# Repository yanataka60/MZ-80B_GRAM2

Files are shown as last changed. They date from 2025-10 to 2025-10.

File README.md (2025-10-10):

# MZ-80B GRAM2ボード

　MZ-80B OWNER'S MANUAL p67「図4-21 グラフィックメモリ2 MZ-8BK(オプション)」回路図から基板を起こしました。

　本体への装着方法は純正品と同じです。

## 回路図
　KiCadフォルダ内のMZ-80B_GRAM2.pdf参照

[回路図](https://github.com/yanataka60/MZ-80B_GRAM2/blob/main/Kicad/MZ-80B_GRAM2.pdf)
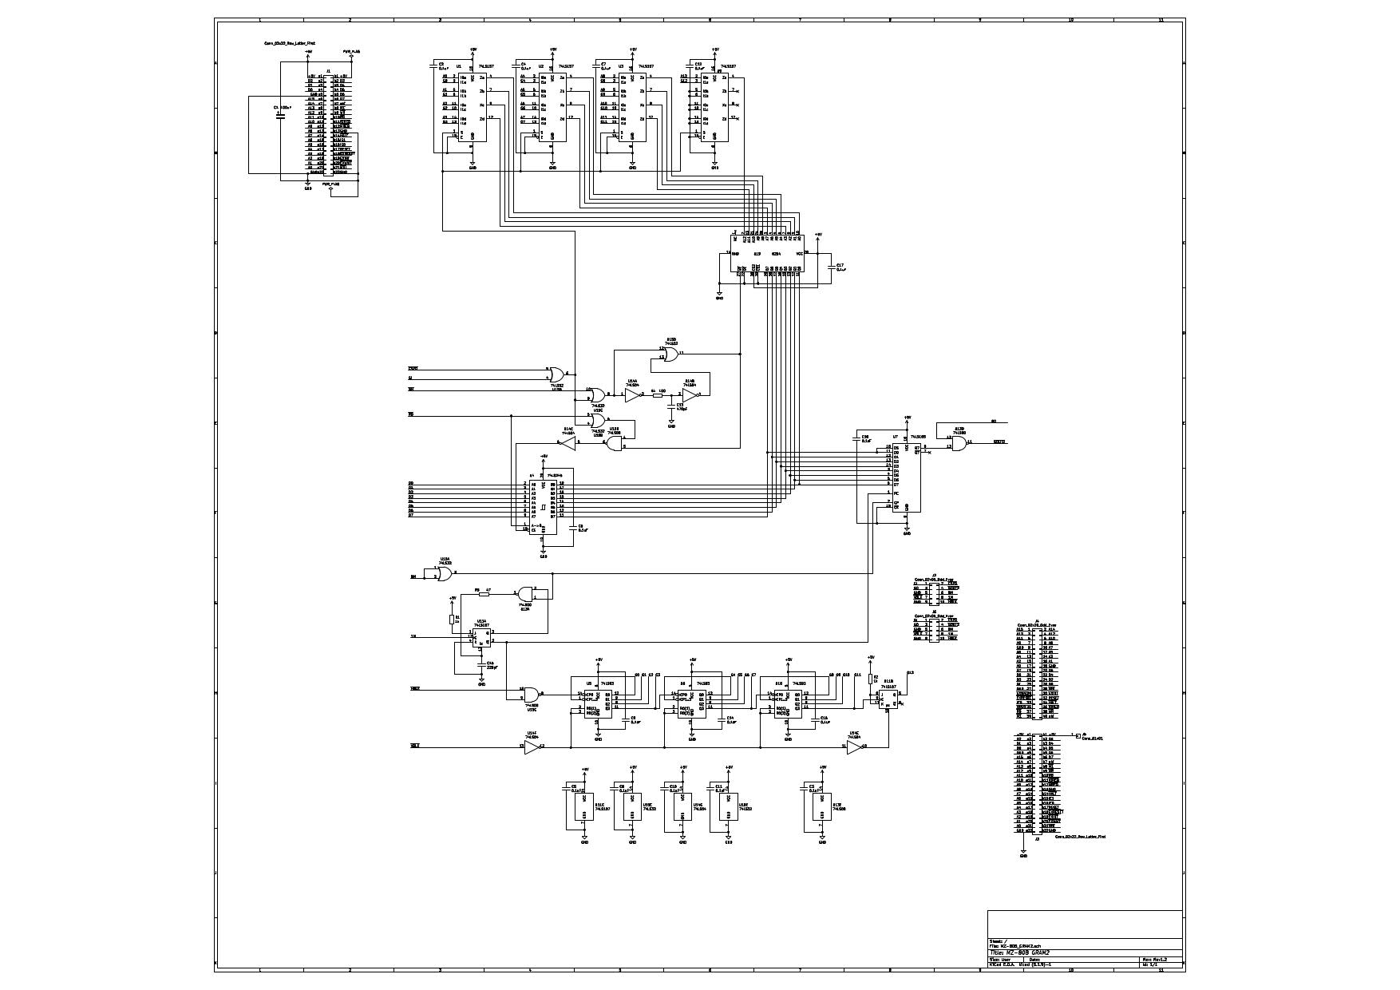
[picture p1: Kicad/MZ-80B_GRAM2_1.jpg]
回路図


## 部品表
|番号|品名|数量|備考|
| --- | --- | --- | --- |
|C1|電解コンデンサ 16V100uF|1||
|C2-C12, C14, C16-C18|積層セラミックコンデンサ 0.1uF|15||
|C13|コンデンサ 470pF|1||
|C15|コンデンサ 220pF|1||
|J2,J3,J4,J5|使用しません|||
|J6|2x5ピンヘッダ|1|秋月電子通商 PH-2x40SG等|
|R1,R2|カーボン抵抗 1k|2||
|R3|カーボン抵抗 47Ω|1||
|R4|カーボン抵抗 100Ω|1||
|U1-U3,U9|74LS157|4|若松通商等|
|U4|74LS245|1|若松通商等|
|U5,U6,U10|74LS93|3|若松通商等|
|U7|74LS165|1|若松通商等|
|U11|74LS107|1|若松通商等|
|U13|74LS00|1|若松通商等|
|U14|74LS04|1|若松通商等|
|U15,U18|74LS32|2|若松通商等|
|U19|8kx8 SRAM 6264|1|若松通商等|
||2x5フラットケーブル|1|4番スロットなら20cm程度、1番スロットなら30cm程度|

## ボードの完成写真
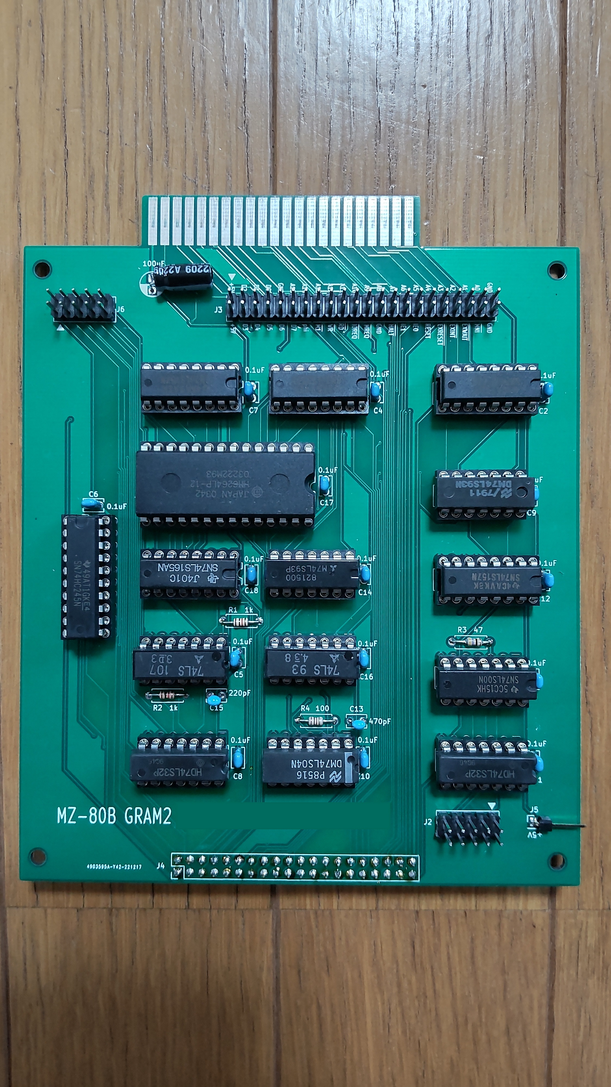
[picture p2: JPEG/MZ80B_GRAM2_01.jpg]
MZ80B_GRAM2_01


## 取付方法
拡張I/Oユニットの1番スロット又は4番スロットにGRAM2ボードを挿し込みます。

GRAM1ボードのJ3とGRAM2ボードのJ6を2x5Pinケーブルで接続します。

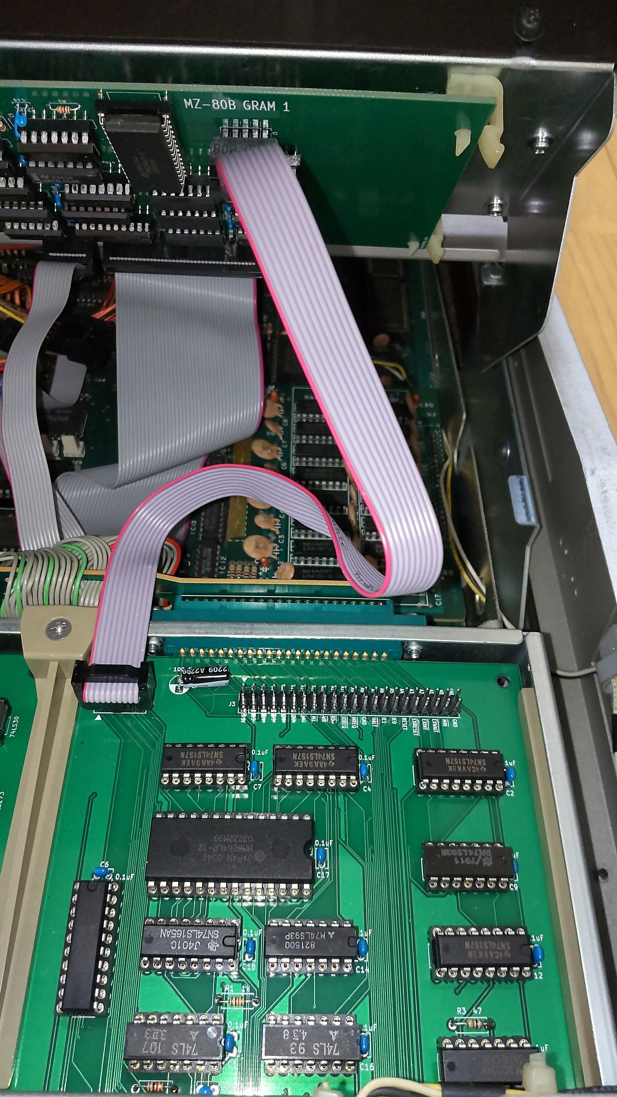
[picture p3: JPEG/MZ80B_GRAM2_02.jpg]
MZ80B_GRAM2_02


## 追記
2025.10.10 回路図のpdfファイルを追加した。

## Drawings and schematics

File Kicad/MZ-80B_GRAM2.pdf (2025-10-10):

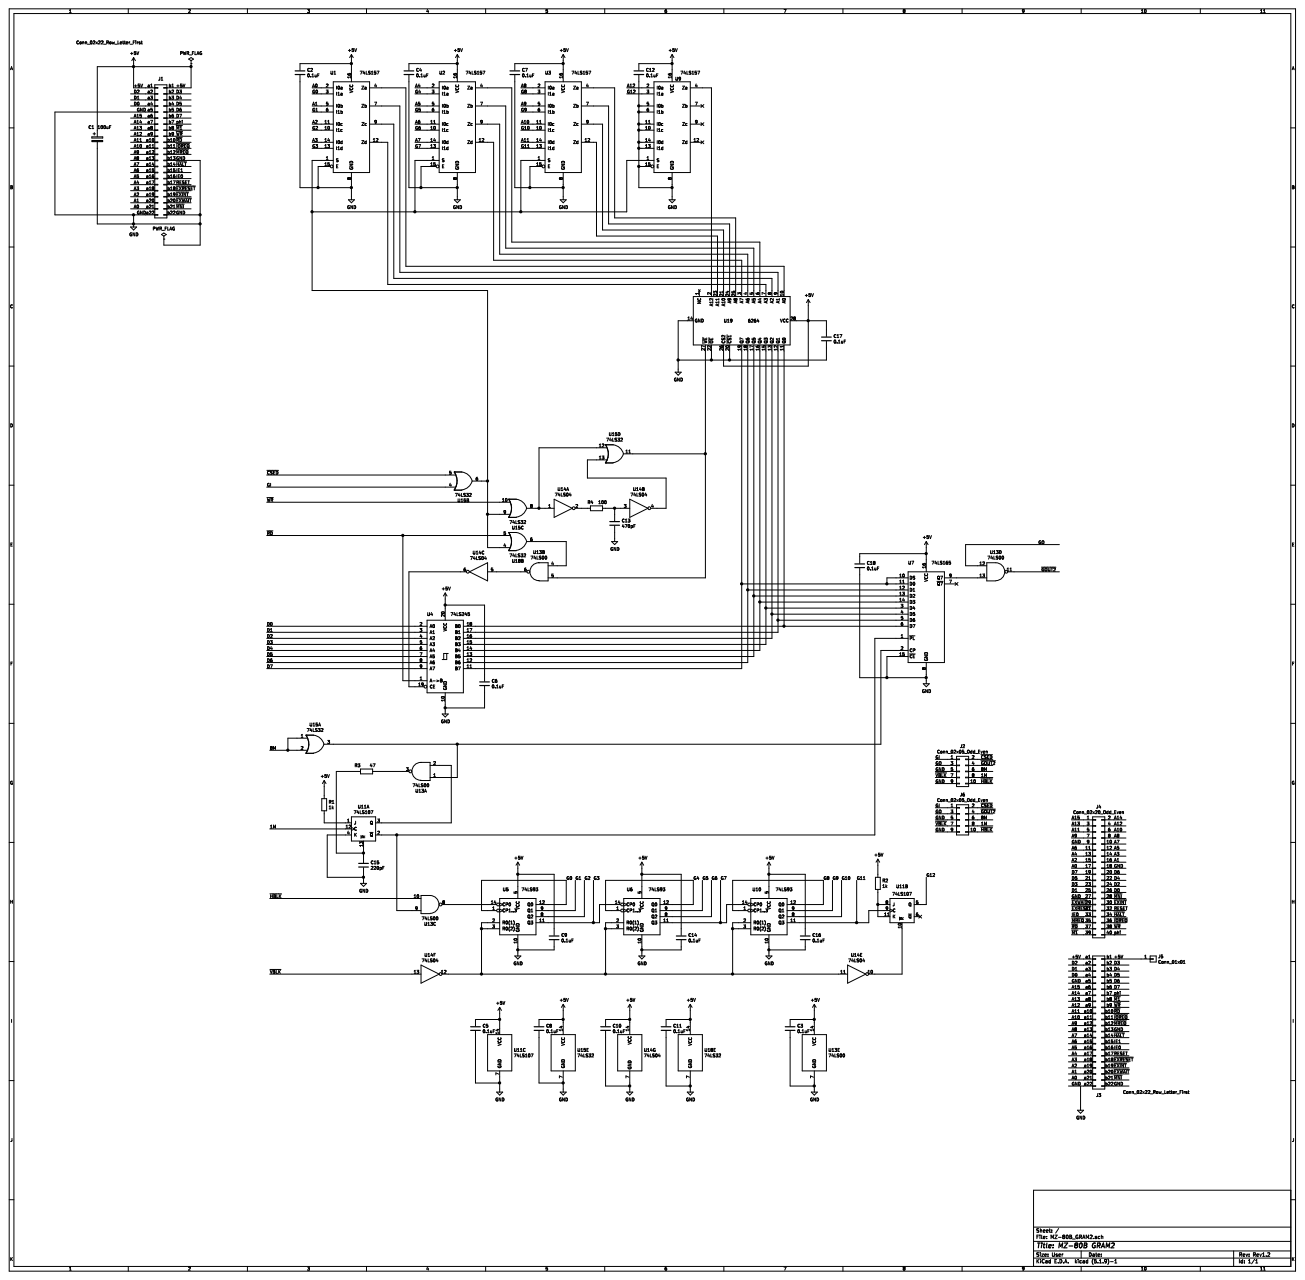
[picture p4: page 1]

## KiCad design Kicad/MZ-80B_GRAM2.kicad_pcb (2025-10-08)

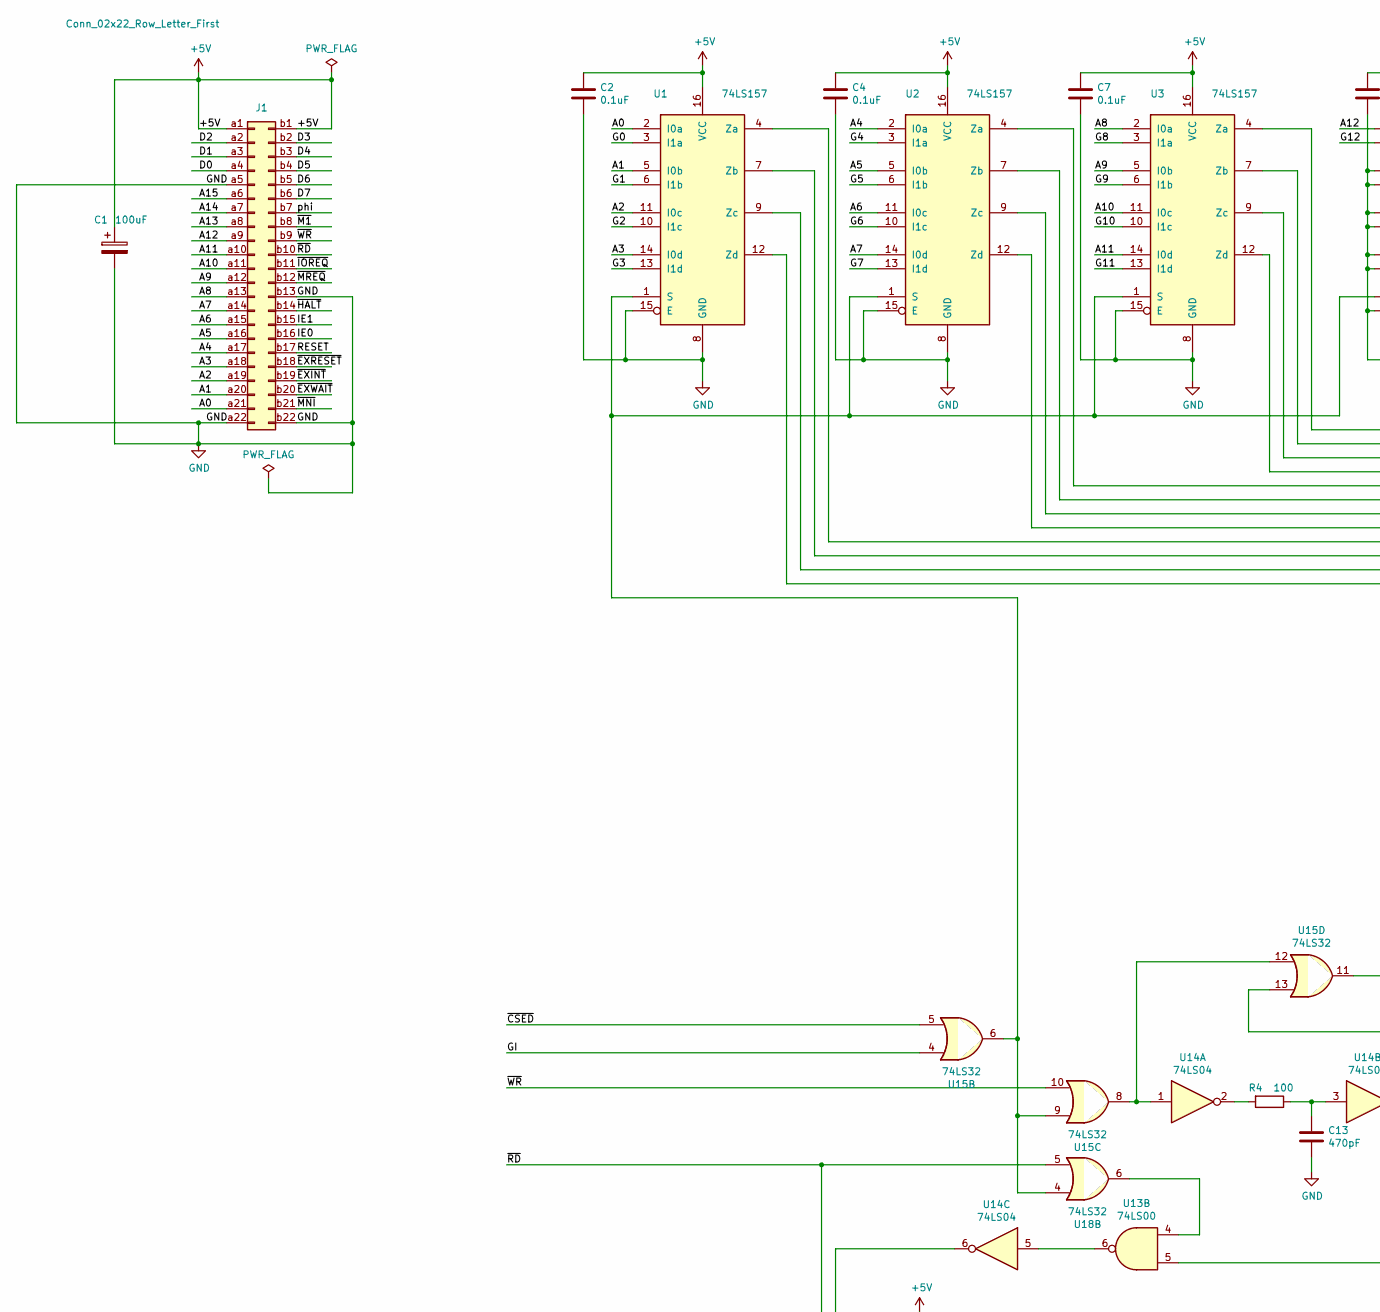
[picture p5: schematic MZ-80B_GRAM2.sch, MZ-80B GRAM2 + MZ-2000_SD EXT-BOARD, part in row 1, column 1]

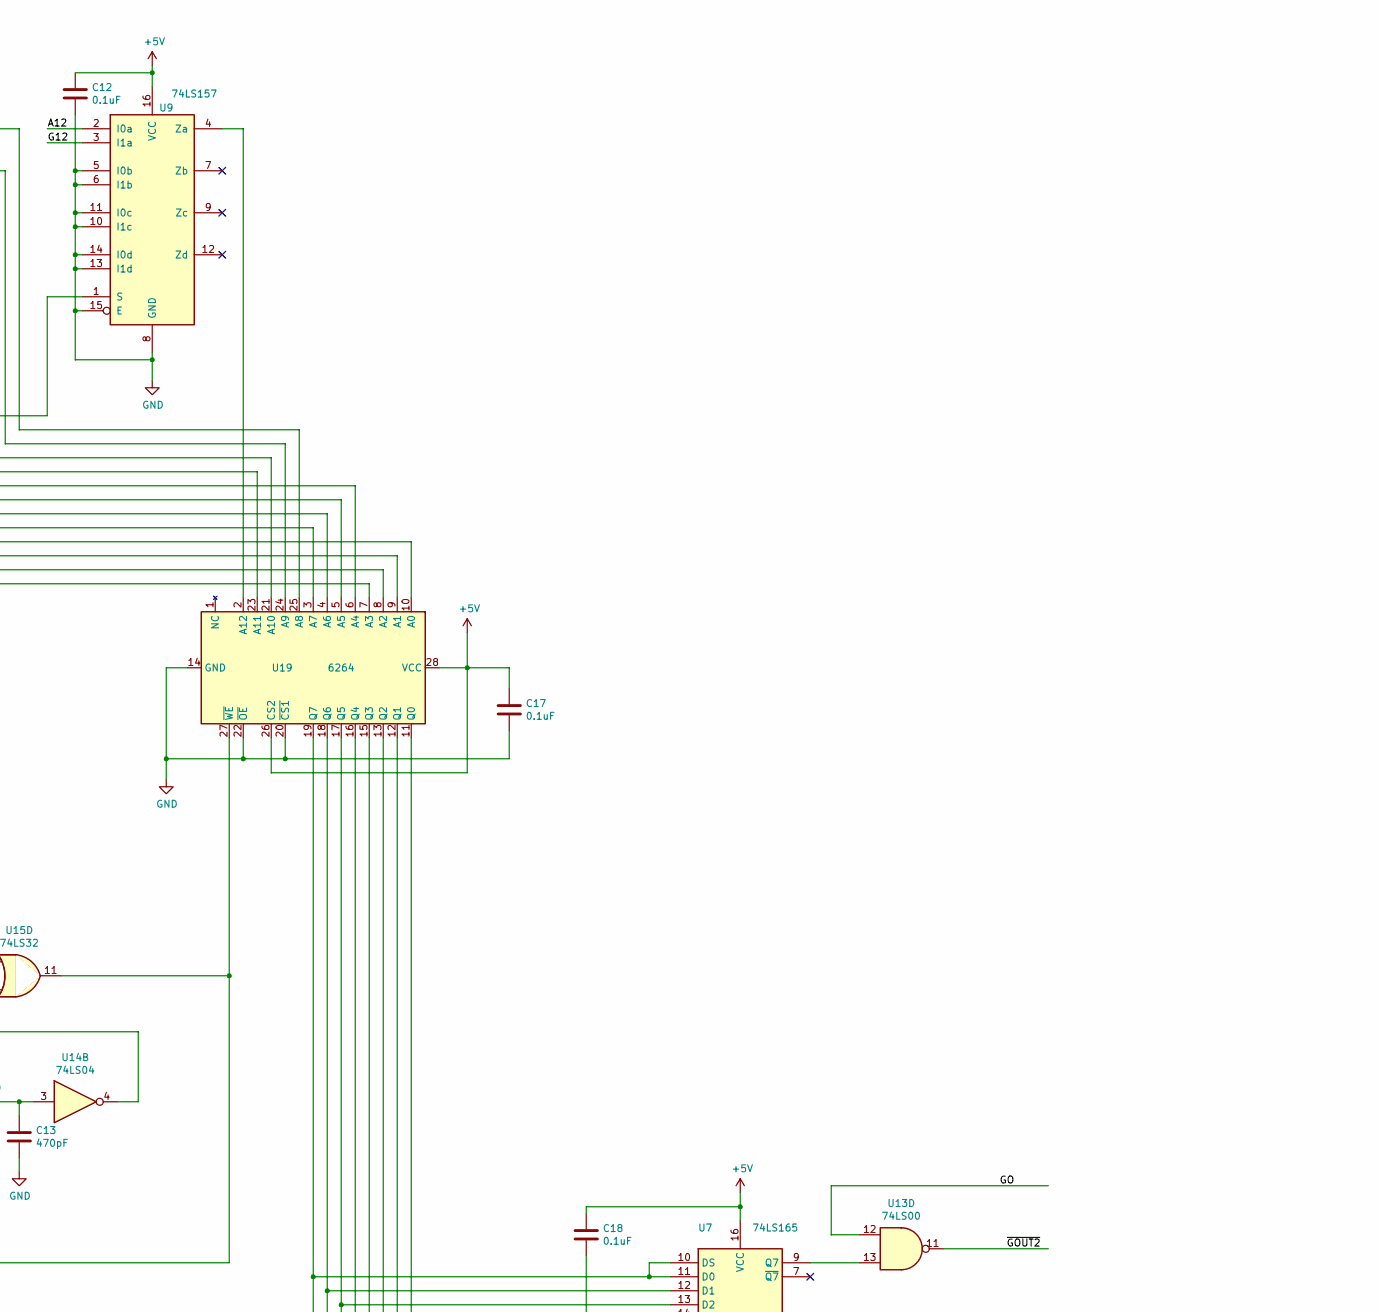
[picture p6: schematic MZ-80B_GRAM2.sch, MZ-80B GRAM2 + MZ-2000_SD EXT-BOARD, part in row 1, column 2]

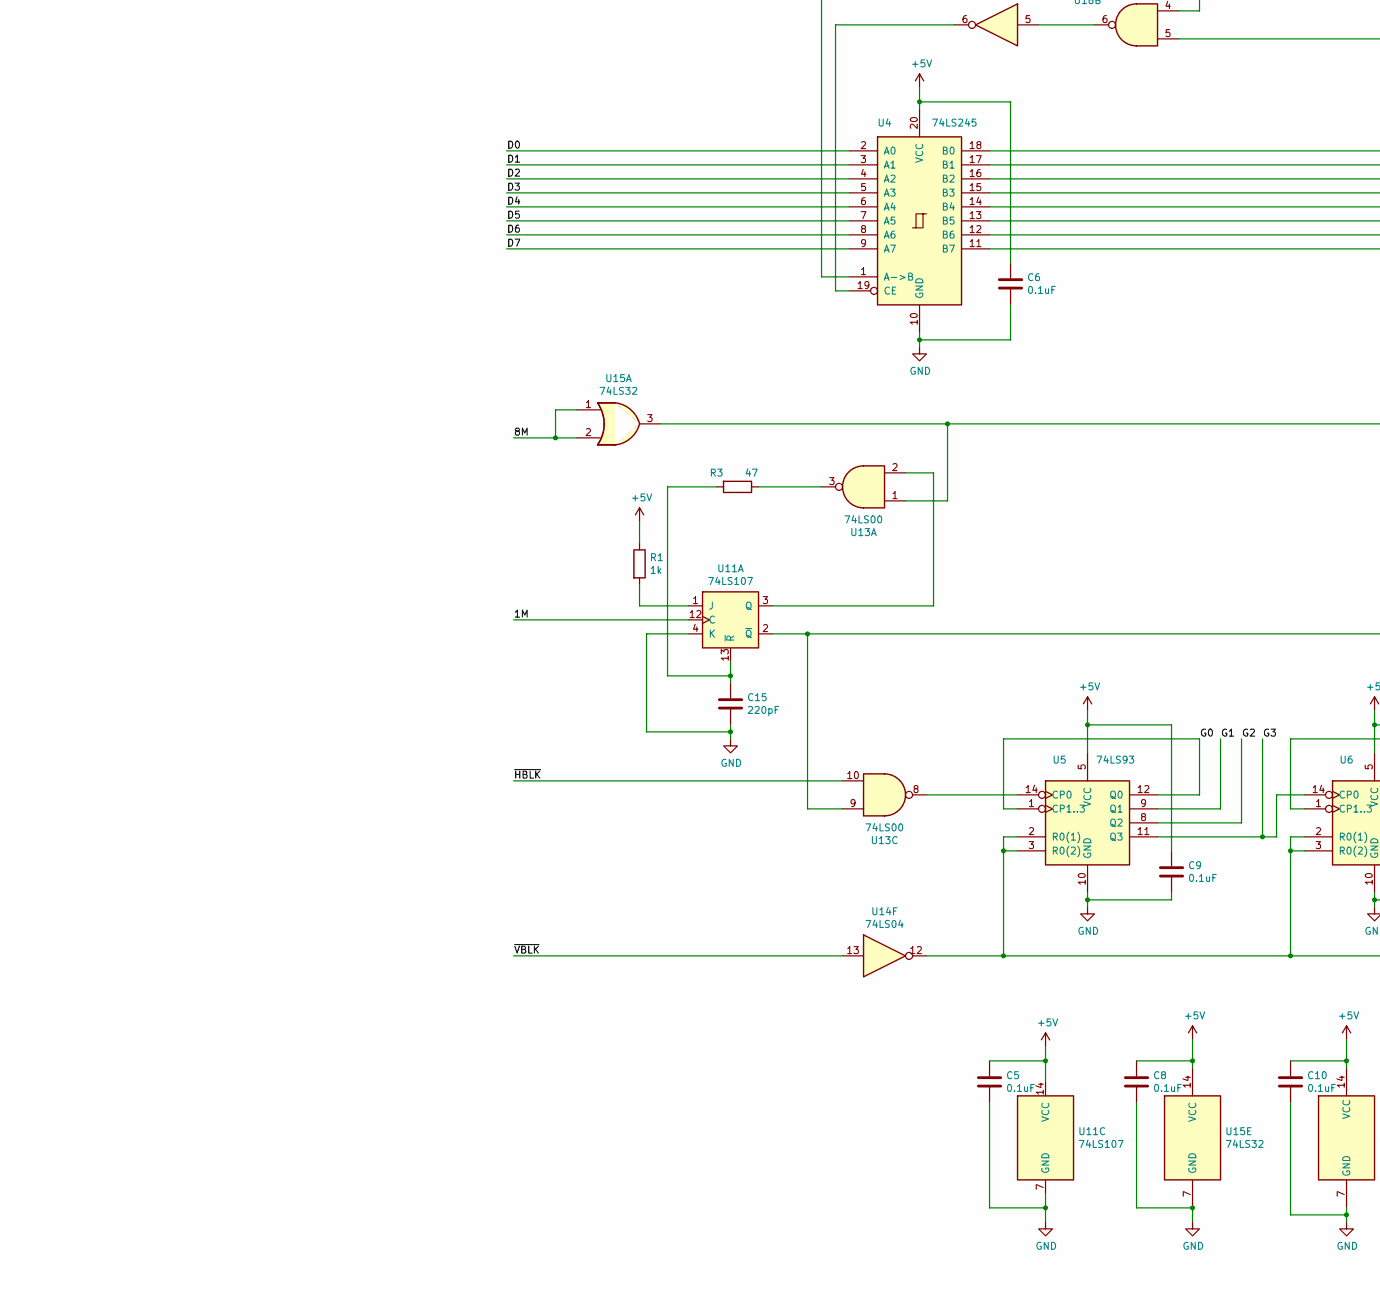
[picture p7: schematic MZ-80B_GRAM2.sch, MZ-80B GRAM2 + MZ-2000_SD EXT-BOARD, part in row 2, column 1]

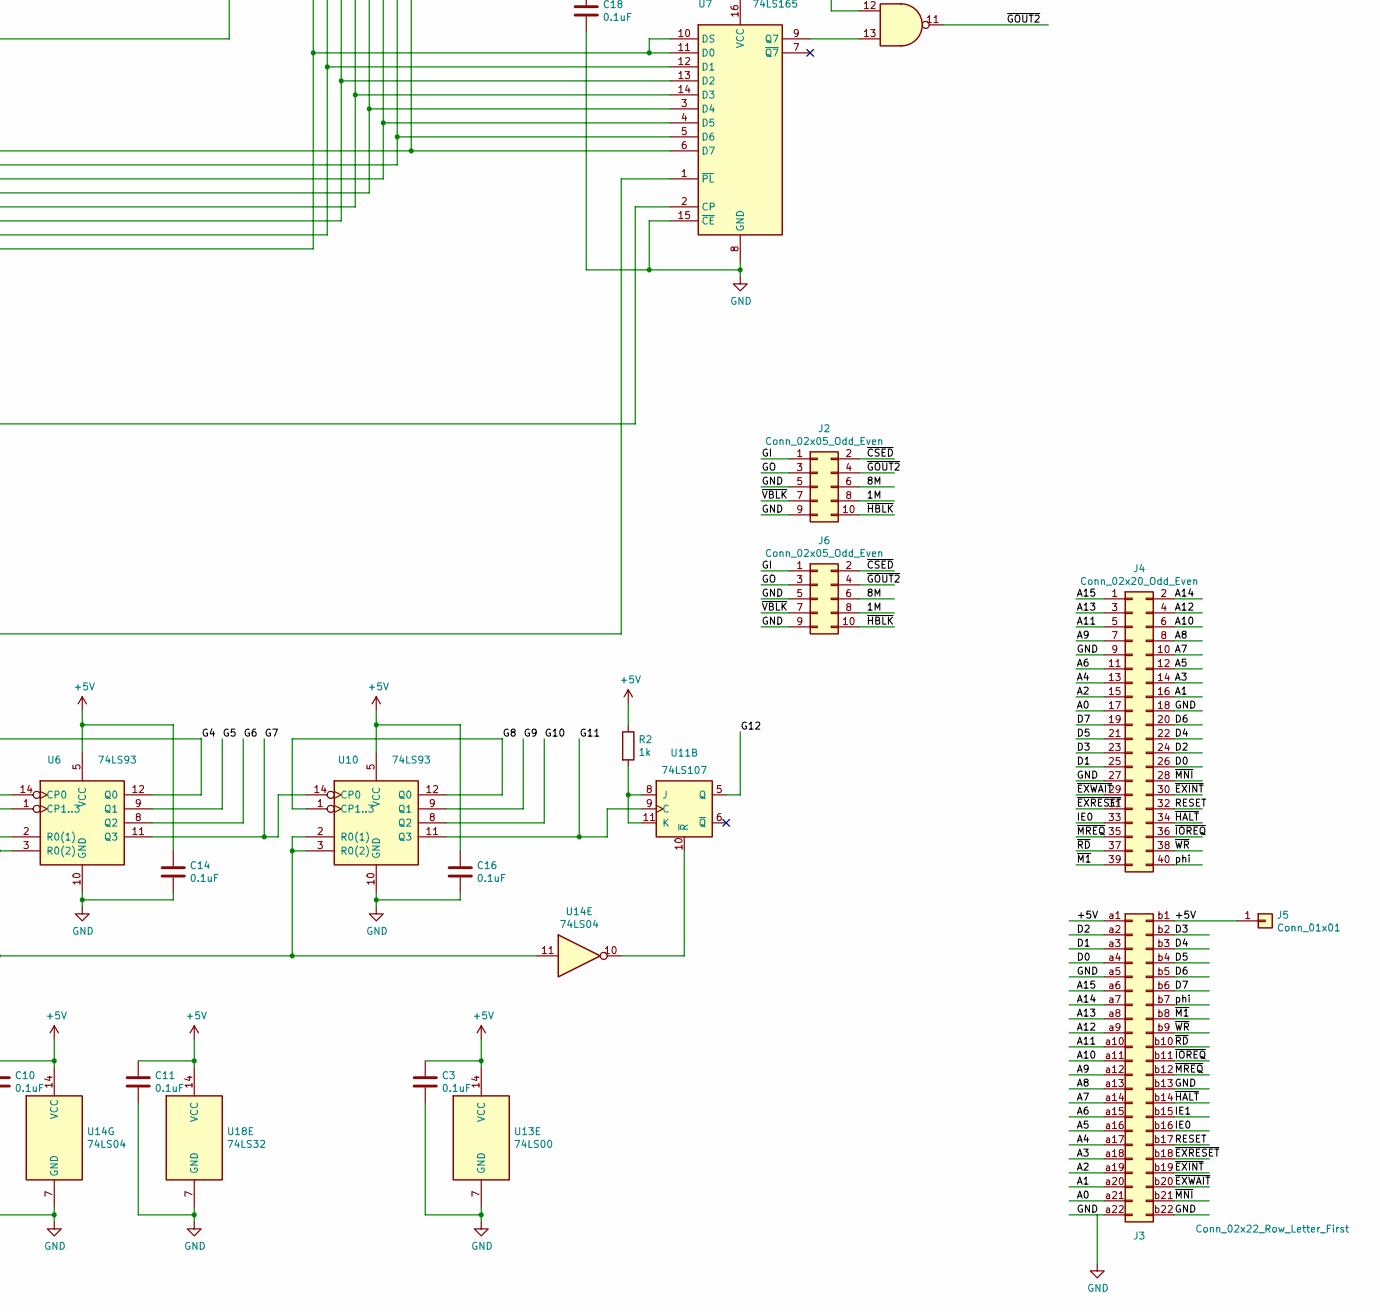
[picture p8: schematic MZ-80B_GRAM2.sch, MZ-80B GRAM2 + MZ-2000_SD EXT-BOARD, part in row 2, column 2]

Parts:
C1: 100uF; CP_Radial_D5.0mm_P2.50mm
C2, C3, C4, C5, C6, C7, C8, C9, C10, C11, C12, C14, C16, C17, C18: 0.1uF; C_Rect_L4.0mm_W2.5mm_P2.50mm
C13: 470pF; C_Rect_L4.0mm_W2.5mm_P2.50mm
C15: 220pF; C_Rect_L4.0mm_W2.5mm_P2.50mm
J1: Conn_02x22_Row_Letter_First; BUS_MZ2000
J2, J6: Conn_02x05_Odd_Even; PinHeader_2x05_P2.54mm_Vertical
J3: Conn_02x22_Row_Letter_First; PinHeader_2x22_P2.54mm_Vertical
J4: Conn_02x20_Odd_Even; PinHeader_2x20_P2.54mm_Vertical
J5: Conn_01x01; PinHeader_1x01_P2.54mm_Vertical
R1, R2: 1k; R_Axial_DIN0207_L6.3mm_D2.5mm_P7.62mm_Horizontal
R3: 47; R_Axial_DIN0207_L6.3mm_D2.5mm_P7.62mm_Horizontal
R4: 100; R_Axial_DIN0207_L6.3mm_D2.5mm_P7.62mm_Horizontal
U1, U2, U3, U9: 74LS157; DIP-16_W7.62mm_LongPads
U4: 74LS245; DIP-20_W7.62mm_LongPads
U5, U6, U10: 74LS93; DIP-14_W7.62mm_LongPads
U7: 74LS165; DIP-16_W7.62mm_LongPads
U11: 74LS107; DIP-14_W7.62mm_LongPads
U13: 74LS00; DIP-14_W7.62mm_LongPads
U14: 74LS04; DIP-14_W7.62mm_LongPads
U15, U18: 74LS32; DIP-14_W7.62mm_LongPads
U19: 6264; DIP-28_W15.24mm_LongPads

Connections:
+5V: C1.1, C2.1, C3.1, C4.1, C5.1, C6.1, C7.1, C8.1, C9.1, C10.1, C11.1, C12.1, C14.1, C16.1, C17.1, C18.1, J1.a1, J1.b1, J3.a1, J3.b1, J5.1, R1.1, R2.1, U1.16 (VCC), U2.16 (VCC), U3.16 (VCC), U4.20 (VCC), U5.5 (VCC), U6.5 (VCC), U7.16 (VCC), U9.16 (VCC), U10.5 (VCC), U11.14 (VCC), U13.14 (VCC), U14.14 (VCC), U15.14 (VCC), U18.14 (VCC), U19.26 (CS2), U19.28 (VCC)
/1M: J2.8, J6.8, U11.12 (C)
/8M: J2.6, J6.6, U15.1, U15.2
/A0: J1.a21, J3.a21, J4.17, U1.2 (I0a)
/A1: J1.a20, J3.a20, J4.16, U1.5 (I0b)
/A2: J1.a19, J3.a19, J4.15, U1.11 (I0c)
/A3: J1.a18, J3.a18, J4.14, U1.14 (I0d)
/A4: J1.a17, J3.a17, J4.13, U2.2 (I0a)
/A5: J1.a16, J3.a16, J4.12, U2.5 (I0b)
/A6: J1.a15, J3.a15, J4.11, U2.11 (I0c)
/A7: J1.a14, J3.a14, J4.10, U2.14 (I0d)
/A8: J1.a13, J3.a13, J4.8, U3.2 (I0a)
/A9: J1.a12, J3.a12, J4.7, U3.5 (I0b)
/A10: J1.a11, J3.a11, J4.6, U3.11 (I0c)
/A11: J1.a10, J3.a10, J4.5, U3.14 (I0d)
/A12: J1.a9, J3.a9, J4.4, U9.2 (I0a)
/A13: J1.a8, J3.a8, J4.3
/A14: J1.a7, J3.a7, J4.2
/A15: J1.a6, J3.a6, J4.1
/D0: J1.a4, J3.a4, J4.26, U4.2 (A0)
/D1: J1.a3, J3.a3, J4.25, U4.3 (A1)
/D2: J1.a2, J3.a2, J4.24, U4.4 (A2)
/D3: J1.b2, J3.b2, J4.23, U4.5 (A3)
/D4: J1.b3, J3.b3, J4.22, U4.6 (A4)
/D5: J1.b4, J3.b4, J4.21, U4.7 (A5)
/D6: J1.b5, J3.b5, J4.20, U4.8 (A6)
/D7: J1.b6, J3.b6, J4.19, U4.9 (A7)
/G0: U1.3 (I1a), U5.1 (CP1..3), U5.12 (Q0)
/G1: U1.6 (I1b), U5.9 (Q1)
/G2: U1.10 (I1c), U5.8 (Q2)
/G3: U1.13 (I1d), U5.11 (Q3), U6.14 (CP0)
/G4: U2.3 (I1a), U6.1 (CP1..3), U6.12 (Q0)
/G5: U2.6 (I1b), U6.9 (Q1)
/G6: U2.10 (I1c), U6.8 (Q2)
/G7: U2.13 (I1d), U6.11 (Q3), U10.14 (CP0)
/G8: U3.3 (I1a), U10.1 (CP1..3), U10.12 (Q0)
/G9: U3.6 (I1b), U10.9 (Q1)
/G10: U3.10 (I1c), U10.8 (Q2)
/G11: U3.13 (I1d), U10.11 (Q3), U11.9 (C)
/G12: U9.3 (I1a), U11.5 (Q)
/GI: J2.1, J6.1, U15.4
/GO: J2.3, J6.3, U13.12
/IE0: J1.b16, J3.b16, J4.33
/IE1: J1.b15, J3.b15
/RESET: J1.b17, J3.b17, J4.32
/phi: J1.b7, J3.b7, J4.40
/~CSED: J2.2, J6.2, U15.5
/~EXINT: J1.b19, J3.b19, J4.30
/~EXRESET: J1.b18, J3.b18, J4.31
/~EXWAIT: J1.b20, J3.b20, J4.29
/~GOUT2: J2.4, J6.4, U13.11
/~HALT: J1.b14, J3.b14, J4.34
/~HBLK: J2.10, J6.10, U13.10
/~IOREQ: J1.b11, J3.b11, J4.36
/~M1: J1.b8, J3.b8, J4.39
/~MNI: J1.b21, J3.b21, J4.28
/~MREQ: J1.b12, J3.b12, J4.35
/~RD: J1.b10, J3.b10, J4.37, U4.1 (A->B), U18.5
/~VBLK: J2.7, J6.7, U14.13
/~WR: J1.b9, J3.b9, J4.38, U15.10
GND: C1.2, C2.2, C3.2, C4.2, C5.2, C6.2, C7.2, C8.2, C9.2, C10.2, C11.2, C12.2, C13.2, C14.2, C15.2, C16.2, C17.2, C18.2, J1.a5, J1.a22, J1.b13, J1.b22, J2.5, J2.9, J3.a5, J3.a22, J3.b13, J3.b22, J4.9, J4.18, J4.27, J6.5, J6.9, U1.8 (GND), U1.15 (E), U2.8 (GND), U2.15 (E), U3.8 (GND), U3.15 (E), U4.10 (GND), U5.10 (GND), U6.10 (GND), U7.8 (GND), U7.15 (~CE), U9.5 (I0b), U9.6 (I1b), U9.8 (GND), U9.10 (I1c), U9.11 (I0c), U9.13 (I1d), U9.14 (I0d), U9.15 (E), U10.10 (GND), U11.4 (K), U11.7 (GND), U13.7 (GND), U14.7 (GND), U15.7 (GND), U18.7 (GND), U19.14 (GND), U19.20 (~CS1), U19.22 (~OE)
unnamed: C13.1, R4.1, U14.3
unnamed: C15.1, R3.2, U11.13 (~R)
unnamed: R1.2, U11.1 (J)
unnamed: R2.2, U11.8 (J), U11.11 (K)
unnamed: R3.1, U13.3
unnamed: R4.2, U14.2
unnamed: U1.1 (S), U2.1 (S), U3.1 (S), U9.1 (S), U15.6, U15.9, U18.4
unnamed: U1.4 (Za), U19.10 (A0)
unnamed: U1.7 (Zb), U19.9 (A1)
unnamed: U1.9 (Zc), U19.8 (A2)
unnamed: U1.12 (Zd), U19.7 (A3)
unnamed: U5.2 (R0(1)), U5.3 (R0(2)), U6.2 (R0(1)), U6.3 (R0(2)), U10.2 (R0(1)), U10.3 (R0(2)), U14.11, U14.12
unnamed: U7.1 (~PL), U11.2 (~Q), U13.9
unnamed: U11.3 (Q), U13.2
unnamed: U11.10 (~R), U14.10
unnamed: U7.2 (CP), U13.1, U15.3
unnamed: U13.4, U18.6
unnamed: U13.5, U15.11, U19.27 (~WE)
unnamed: U13.6, U14.5
unnamed: U5.14 (CP0), U13.8
unnamed: U7.9 (Q7), U13.13
unnamed: U14.1, U15.8, U15.12
unnamed: U14.4, U15.13
unnamed: U4.19 (CE), U14.6
unnamed: U9.4 (Za), U19.2 (A12)
unnamed: U2.12 (Zd), U19.3 (A7)
unnamed: U2.9 (Zc), U19.4 (A6)
unnamed: U2.7 (Zb), U19.5 (A5)
unnamed: U2.4 (Za), U19.6 (A4)
unnamed: U4.18 (B0), U7.6 (D7), U19.11 (Q0)
unnamed: U4.17 (B1), U7.5 (D6), U19.12 (Q1)
unnamed: U4.16 (B2), U7.4 (D5), U19.13 (Q2)
unnamed: U4.15 (B3), U7.3 (D4), U19.15 (Q3)
unnamed: U4.14 (B4), U7.14 (D3), U19.16 (Q4)
unnamed: U4.13 (B5), U7.13 (D2), U19.17 (Q5)
unnamed: U4.12 (B6), U7.12 (D1), U19.18 (Q6)
unnamed: U4.11 (B7), U7.10 (DS), U7.11 (D0), U19.19 (Q7)
unnamed: U3.9 (Zc), U19.21 (A10)
unnamed: U3.12 (Zd), U19.23 (A11)
unnamed: U3.7 (Zb), U19.24 (A9)
unnamed: U3.4 (Za), U19.25 (A8)

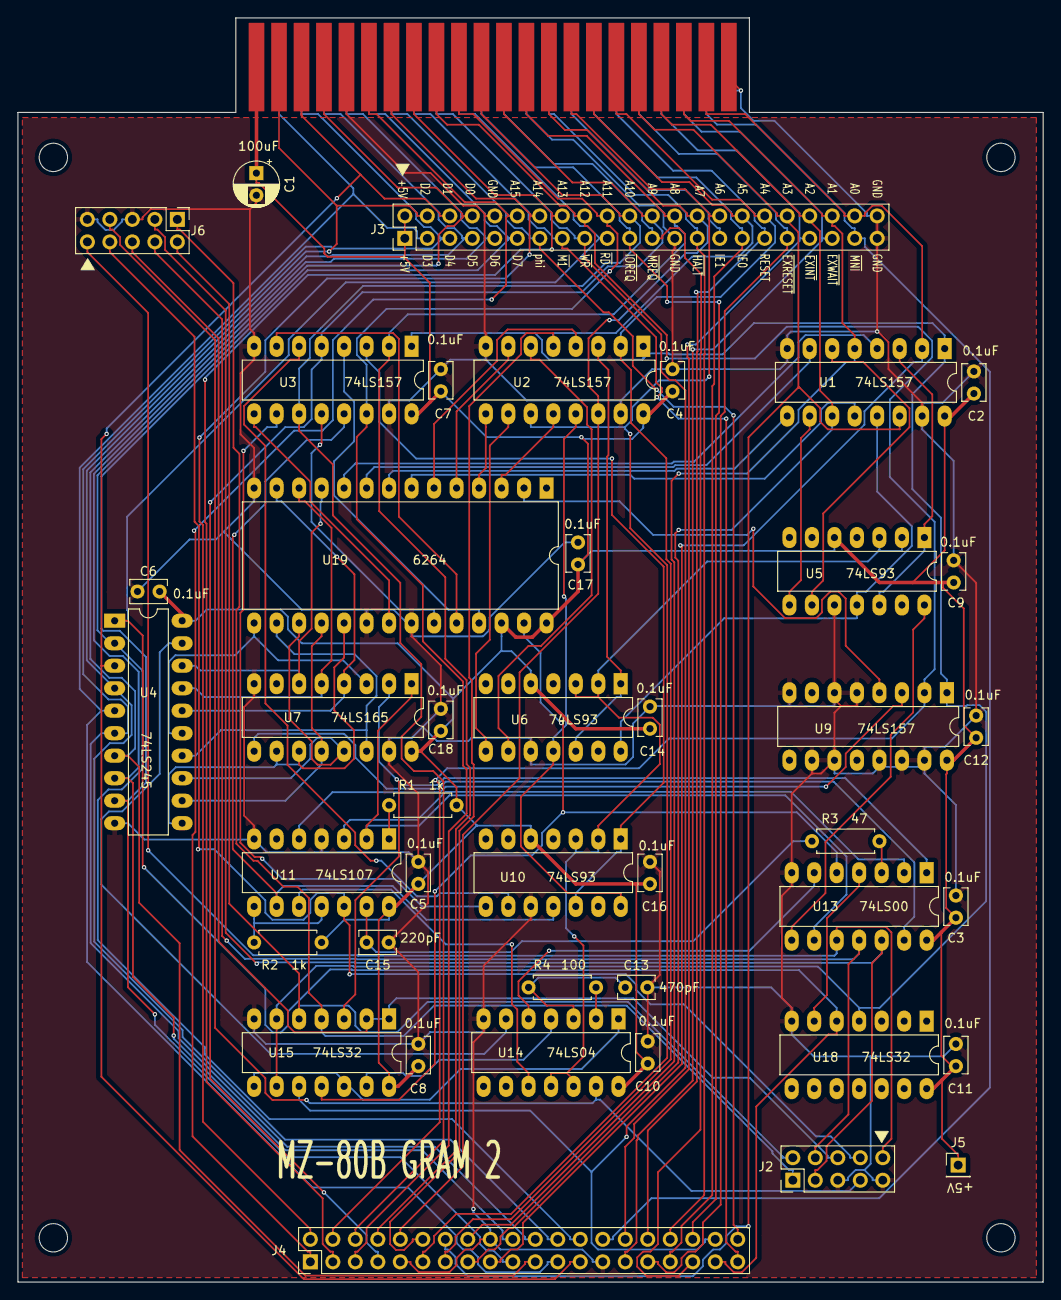
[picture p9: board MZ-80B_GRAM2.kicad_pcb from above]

Board: 2 copper layers, 115.8 x 142.7 mm, 47 parts (0 on the bottom side), 102 nets.

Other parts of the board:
MH1, MH2, MH3, MH4: MountingHole_3.2mm_M3
